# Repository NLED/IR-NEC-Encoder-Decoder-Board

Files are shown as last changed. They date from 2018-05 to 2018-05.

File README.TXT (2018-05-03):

THERE IS NO WARRANTY FOR THE PROGRAM, TO THE EXTENT PERMITTED BY APPLICABLE LAW. 
EXCEPT WHEN OTHERWISE STATED IN WRITING THE COPYRIGHT HOLDERS AND/OR OTHER PARTIES 
PROVIDE THE PROGRAM “AS IS” WITHOUT WARRANTY OF ANY KIND, EITHER EXPRESSED OR IMPLIED,
INCLUDING, BUT NOT LIMITED TO, THE IMPLIED WARRANTIES OF MERCHANTABILITY AND FITNESS 
FOR A PARTICULAR PURPOSE. THE ENTIRE RISK AS TO THE QUALITY AND PERFORMANCE OF THE 
PROGRAM IS WITH YOU. SHOULD THE PROGRAM PROVE DEFECTIVE, YOU ASSUME THE COST OF ALL 
NECESSARY SERVICING, REPAIR OR CORRECTION.

 Original Author: Jeffrey Nygaard
 Company: Northern Lights Electronic Design, LLC
 Date: May 5, 2018
 Contact: JNygaard@NLEDshop.com
 Copyright© 2018 by Northern Lights Electronic Design, LLC. All Rights Reserved
 
;=============          www.NLEDShop.com/addoncards           ============
;=============     www.NorthernLightsElectronicDesign.com       ============

This work is licensed under a Attribution-NonCommercial 4.0 International (CC BY-NC 4.0)
https://creativecommons.org/licenses/by-nc/4.0/legalcode

Free to use for personal use, but please attribute the original author.

Commercial licenses versions are available for a donation of any amount. Contact JNygaard@NLEDshop.com for details.

================================================================================================================

Ready-made devices are available for purchase, and large batch manufacturing of any device can be requested.
Please see the webpage www.NLEDShop.com/addoncards

NLED is available for custom design and manufacturing, please contact via phone or email to discuss your project.

================================================================================================================

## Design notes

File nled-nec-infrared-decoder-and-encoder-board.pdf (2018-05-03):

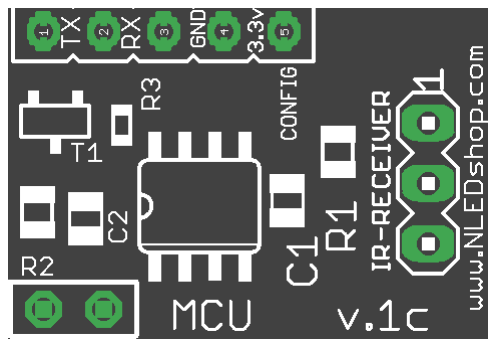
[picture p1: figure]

## Specification:

Input Voltage
Logic Current Draw
Connectors
Connector Spacing
PCB Dimension - Inch
PCB Dimension - Metric
Infrared Remote Compatbility

3.3v or 5v*
< 50mA
Solder Pads
0.1”(2.54mm)
0.8” x 0.55”
20.5mm x 14mm
N.E.C

Receives a raw modulated or demodulated NEC IR signal and converts it into bytes that are sent out the serial port. The serial baud rate is selectable from two default speeds. The default usage mode transmits out a command sequence with framing bytes, address high, address low, and the validated command byte. This device is designed to remove the work load of protocol decoding from the main processor, which could be a PIC, Arduino, FTDI, or other similar serial capable device. It supports full duplex communication when using an I.R. transceiver.

The output protocol was written to be easy to receive. The values 255 & 254 for byte framing followed by data bytes, the repeat codes are indicated by 250 & 253. None of those values would normally be in a NEC command sequence, or at least not in that order. Device expects the extended NEC Protocol, with 16-bit Address, rather than the specified 8-bit address with 8-bit inverse.This device accepts all addresses, and passes the received address to the host device.

## Features:

*Ensure all other connected devices are 5 volt tolerant. That includes IR modules and connected serial devices. *Board lables may say 3.3v but it could also be 5 volt .

- Reduces embedded program work load and simplifies code, this device handles the protocol conversion and outputs easy to understand serial bytes.
- Full transceiver support, recieve and transmit I.R. signals.
- Supports modulated recievers such as the TSOP38238.
- Supports demodulated transcievers such as the TFBS4711.
- Compatible with many standard remote controllers, such as many of the cheaper Chinese ones.
- Compatible with almost all NLED Controllers.
- Very small size.
- Easy to wire remotely, place the receiver where it will best recieve the IR signal.
- Open Source & Open Hardware - Free and open to all for non-commercial use. Contact for commerical.
- Hardware could be used for other IR protocols such as RC-5 or others.
- Standard 8-N-1 at two baud rates available for serial communication.

## NLED NEC Infrared Decoder and Encoder

Pg. 1

TOP

BOTTOM

www.NLEDShop.com/addoncards | www.NorthernLightsElectronicDesign.com

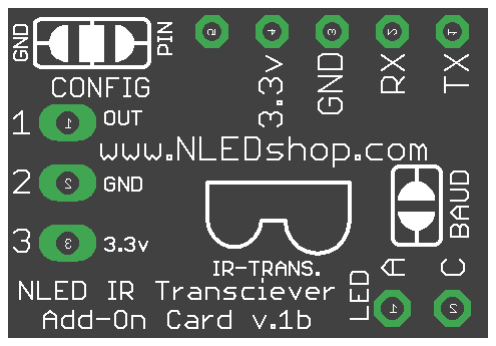
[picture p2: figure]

Datasheet Revision: 1 | Hardware Revision: 1

Copyright Northern Lights Electronic Design, LLC ©2018 - 2/20/2018 - NLED-ADDON-NECIR-V1A - Support@NLEDshop.com

Firmware Revision: 1

This device uses a PIC12F microcontroller to receive infrared signals from remote controls. The received signal is decoded and the NEC protocol is converted to a custom serial packet that is sent out the microcontroller’s UART. The serial packets are easily read and decoded by the receiving device, that device can then decide how to parse the received commands and data.

This device supports demodulated reception from standard IR receiving modules. And modulated reception and transmission from transcievers.

Code Reception UART Output: 255 -> 254 -> AdrMSB -> AdrLSB -> Remote Key Number

Note: NEC sends LSB first for extended address, UART transmits MSB first since that is a common standard.

Example:
AddressLow - 0x00, AddressHi - 0xEF, KeyID#4(key IDnumbers start at 0)
255 -> 254 -> 239(0xEF) -> 0(0x00) -> 4
Repeat: 250 -> 253, repeats while key is being held pressed.

## Reception Usage Description

## Firmware Info

The firmware is written for the NEC protocol, which uses a 38KHz carrier frequency. Using the SMD solder jumpers, the function can be selected.

CONFIG Jumper: Connects to Configuration Mode and MCLR(for ICSP programming) function. For ICSP programming, the jumper must be tied to “PIN”. For application usage, the jumper selects if the device should expect a moduled signal(from the transciever) or a demodulated signal(from the receiver). Connecting the jumper to “PIN”(or left unconnected) will select demoduled receiver functions, if the jumper is tied to “GND” a modulated signal is expected.

BAUD Jumper: Selects either slow or fast baud rate. The default firmwae uses 19,200 baud for slow, and 250,000 baud for fast. Leave jumper open/untied for slow baud rate, and close the jumper for fast baud rate.

This device can also transmit a NEC control command. Either an I.R. LED must be connected to the LED pads, or the transceiver must be used. The protocol is not much different than receiving, the host device just sends a series of serial bytes to the device. The serial bytes include an unlock sequence, followed by the command IDs the user wants to send.

Serial Transmission From Host: 251 -> 122 -> 252 -> 123 -> AdrMSB -> AdrLSB -> Command -> Number of repeats

The (251 -> 122 -> 252 -> 123) is the unlock sequence, required to frame the data and validate a command to the device.

Note: If compiling the firmware make sure “cEnableNECTransmission” is defined. Also the firmware has another flag that tells the firmware to ignore reception during transmisison to prevent receiving its own command.

## Transmission Usage Description

This project’s source files, including Eagle schematic and board files, MPLABX project, and support documents are all open source and available for free.

The project is released under Attribution-NonCommercial 4.0 International. A commercial licence is available as donation-ware of any amount. Contact JNygaard@NLEDshop.com for details.

## Open Source / Open Platform

## Part Selection

MCU:
For Infrared Reception Only PIC12F1822 or PIC12F1840

For Full Duplex Infrared:
PIC12F1572

These are not the only options.

Infrared Receiver/Transciever: For Infrared Reception Only: TSOP3828

For Full Duplex Infrared:
Vishay TFBS4711

These are not the only options.

C1 & C2 - 01.uF, 0805, >=6.3vdc

For Transceiver/Transmission Use:

R1 - 47ohm, 0805
R2 - 18 to 47 ohm, 0805
R3 - 5 to 10 ohm, 0805
T1 - NPN Transistor, BSR17A, SOT-23

The I.R. LED is used for transmitting command codes, a standard 5mm dome LED is recommended. Higher power I.R. LEDs could be used, check the transistor rating and current limiting resistor values. The I.R. LED can be wired to the device or can be mounted directly to the circuit board.

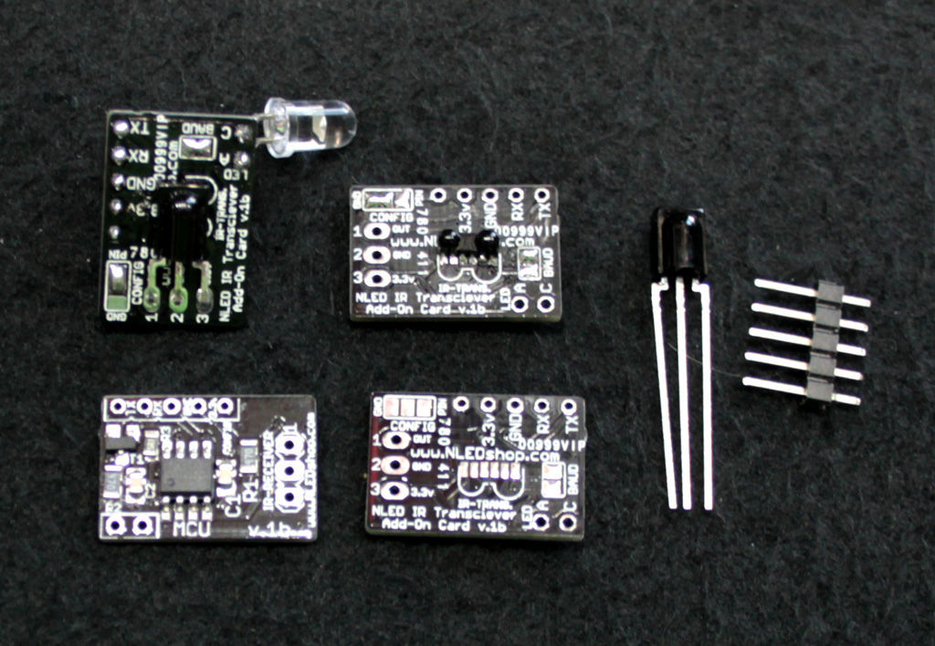
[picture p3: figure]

## Assembly Options

Image to the left is a few ways to configure the device and the parts that could be used.

## Hardware Diagrams

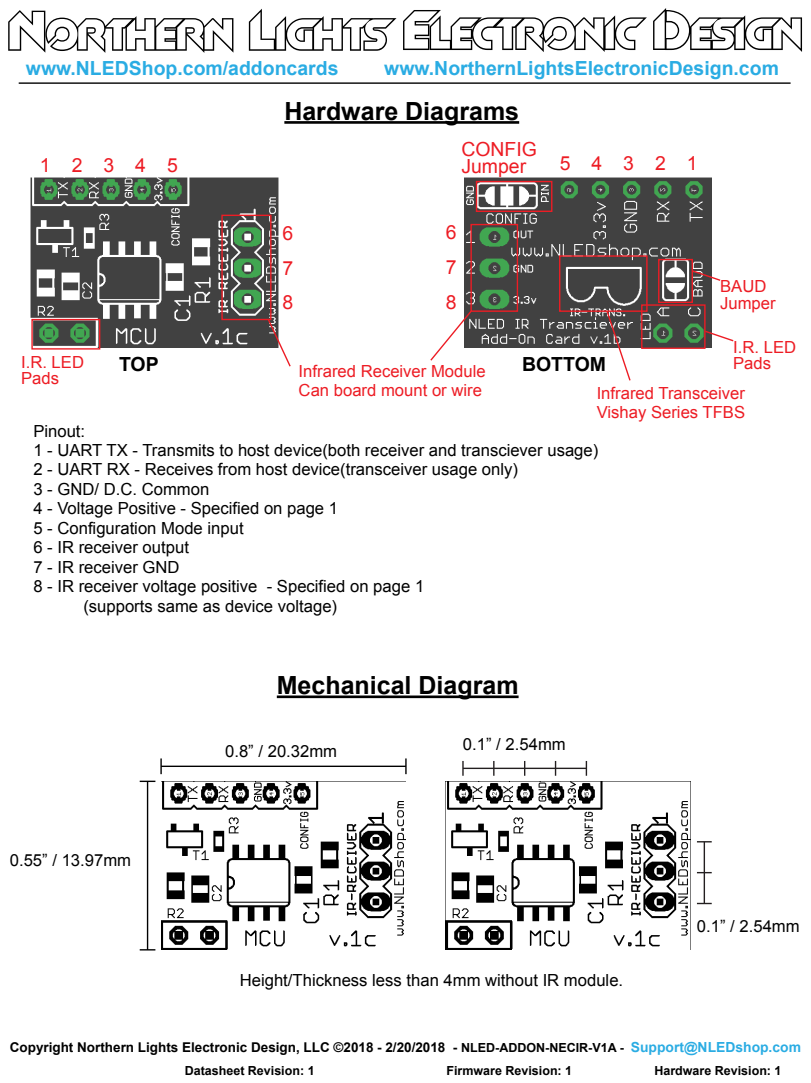
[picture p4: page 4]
TOP; BOTTOM; CONFIG Jumper; BAUD Jumper; I.R. LED; Pads; Mechanical Diagram

Infrared Receiver Module
Can board mount or wire

Infrared Transceiver
Vishay Series TFBS

Pinout:
1 - UART TX - Transmits to host device(both receiver and transciever usage)
2 - UART RX - Receives from host device(transceiver usage only)
3 - GND/ D.C. Common
4 - Voltage Positive - Specified on page 1
5 - Configuration Mode input
6 - IR receiver output
7 - IR receiver GND
8 - IR receiver voltage positive - Specified on page 1

(supports same as device voltage)

Height/Thickness less than 4mm without IR module.

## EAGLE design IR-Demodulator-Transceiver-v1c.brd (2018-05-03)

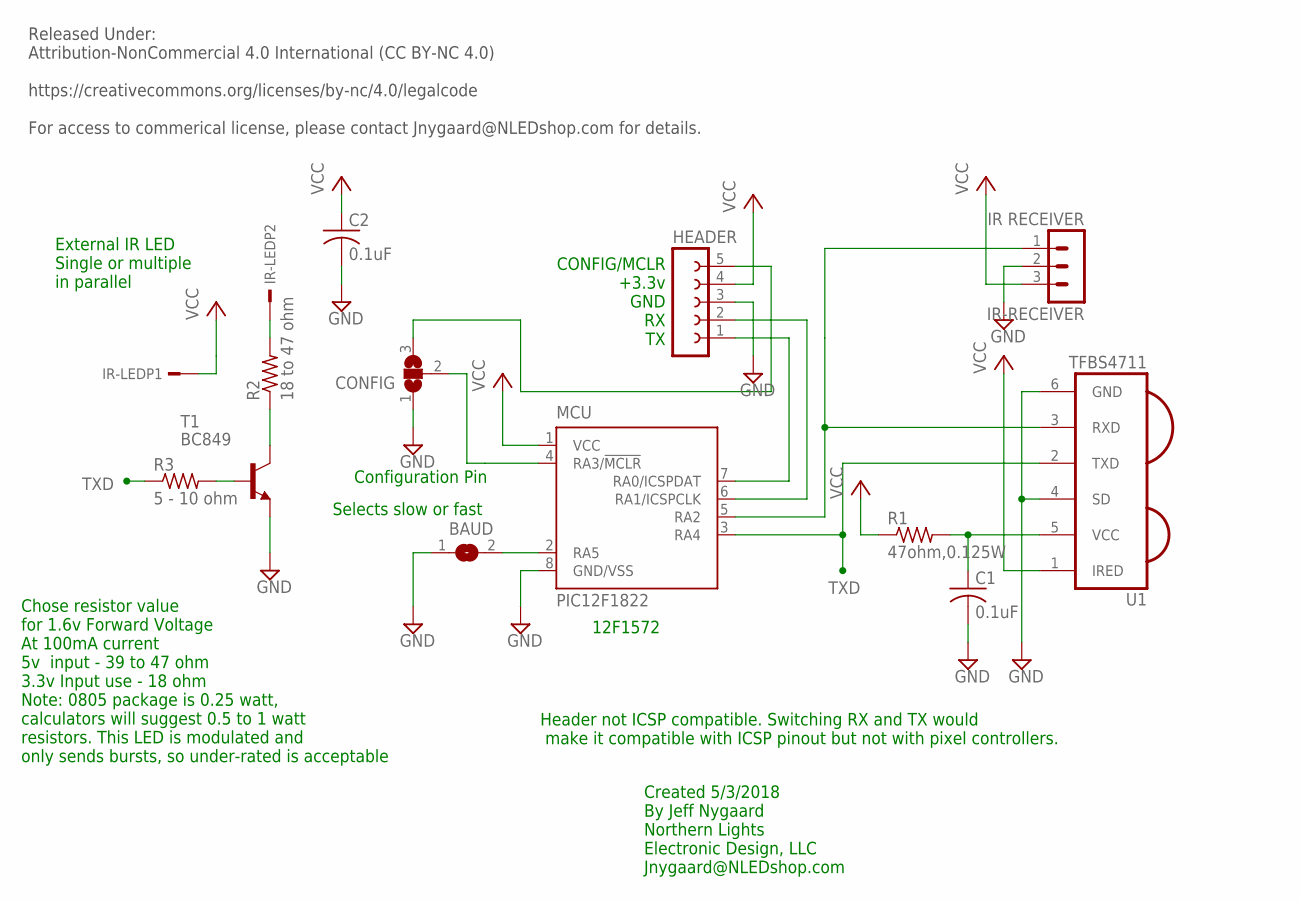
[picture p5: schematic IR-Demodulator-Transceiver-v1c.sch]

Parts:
BAUD: SJ
C1, C2: 0.1uF; C0805
CONFIG: SJ2W; SJ_2
HEADER: FE05-1
IR-LED: HEADER-2X1
IR-RECEIVER: IR RECEIVER; MA03-1
MCU: PIC12F1822; SOIC-8
R1: 47ohm,0.125W; R0805
R2: 18 to 47 ohm; R0805
R3: 5 - 10 ohm; R0603
T1: BC849; SOT23
U1: TFBS4711

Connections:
GND: BAUD.1, C1.2, C2.2, CONFIG.1, HEADER.3, IR-RECEIVER.2, MCU.8 (GND/VSS), T1.2 (E), U1.4 (SD), U1.6 (GND)
IRRX: IR-RECEIVER.1, MCU.5 (RA2), U1.3 (RXD)
unnamed: R3.2, T1.1 (B)
unnamed: BAUD.2, MCU.2 (RA5)
unnamed: C1.1, R1.2, U1.5 (VCC)
unnamed: CONFIG.3, HEADER.5
unnamed: HEADER.1, MCU.7 (RA0/ICSPDAT)
unnamed: HEADER.2, MCU.6 (RA1/ICSPCLK)
unnamed: CONFIG.2, MCU.4 (RA3/!MCLR)
unnamed: IR-LED.2, R2.2
unnamed: R2.1, T1.3 (C)
TXD: MCU.3 (RA4), R3.1, U1.2 (TXD)
VCC: C2.1, HEADER.4, IR-LED.1, IR-RECEIVER.3, MCU.1 (VCC), R1.1, U1.1 (IRED)

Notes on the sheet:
CONFIG/MCLR +3.3v GND RX TX
Selects slow or fast
Configuration Pin
Header not ICSP compatible. Switching RX and TX would make it compatible with ICSP pinout but not with pixel controllers.
External IR LED Single or multiple in parallel
Chose resistor value for 1.6v Forward Voltage At 100mA current 5v input - 39 to 47 ohm 3.3v Input use - 18 ohm Note: 0805 package is 0.25 watt, calculators will suggest 0.5 to 1 watt resistors. This LED is modulated and only sends bursts, so under-rated is acceptable
12F1572
Released Under: Attribution-NonCommercial 4.0 International (CC BY-NC 4.0) https://creativecommons.org/licenses/by-nc/4.0/legalcode For access to commerical license, please contact Jnygaard@NLEDshop.com for details.
Created 5/3/2018 By Jeff Nygaard Northern Lights Electronic Design, LLC Jnygaard@NLEDshop.com

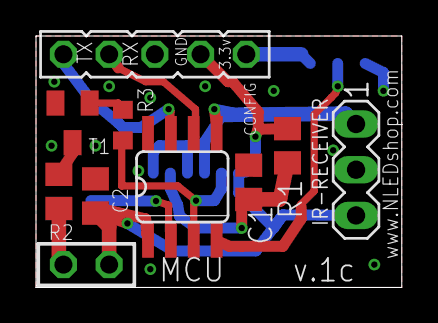
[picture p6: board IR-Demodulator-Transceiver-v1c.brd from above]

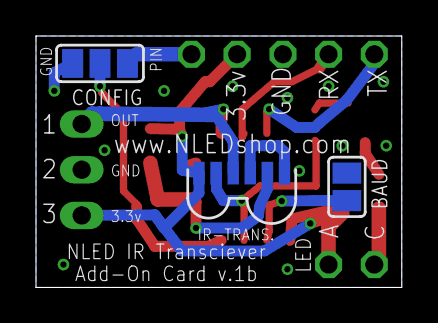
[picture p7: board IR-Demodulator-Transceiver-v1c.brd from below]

Board: 2 copper layers, 20.3 x 14.0 mm, 13 parts (3 on the bottom side), 13 nets.

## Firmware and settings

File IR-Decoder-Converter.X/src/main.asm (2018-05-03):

;*******************************************************************************                                        *
;                                                                              *
;    SOFTWARE IS PROVIDED "AS IS".  Northern Lights Electronic Design, LLC AND ITS LICENSORS EXPRESSLY      *
;    DISCLAIM ANY WARRANTY OF ANY KIND, WHETHER EXPRESS OR IMPLIED, INCLUDING  *
;    BUT NOT LIMITED TO, THE IMPLIED WARRANTIES OF MERCHANTABILITY, FITNESS    *
;    FOR A PARTICULAR PURPOSE, OR NON-INFRINGEMENT. IN NO EVENT SHALL          *
;    Northern Lights Electronic Design, LLC OR ITS LICENSORS BE LIABLE FOR ANY INCIDENTAL, SPECIAL,         *
;    INDIRECT OR CONSEQUENTIAL DAMAGES, LOST PROFITS OR LOST DATA, HARM TO     *
;    YOUR EQUIPMENT, COST OF PROCUREMENT OF SUBSTITUTE GOODS, TECHNOLOGY OR    *
;    SERVICES, ANY CLAIMS BY THIRD PARTIES (INCLUDING BUT NOT LIMITED TO ANY   *
;    DEFENSE THEREOF), ANY CLAIMS FOR INDEMNITY OR CONTRIBUTION, OR OTHER      *
;    SIMILAR COSTS.                                                            *
;                                                                              *
;    To the fullest extend allowed by law, Northern Lights Electronic Design, LLC and its licensors         *
;    liability shall not exceed the amount of fee, if any, that you have paid directly to NLED to use this software.
;                                                                              *
;    Northern Lights Electronic Design, LLC PROVIDES THIS SOFTWARE CONDITIONALLY UPON YOUR ACCEPTANCE OF
;    THESE TERMS.                                                              *
;                                                                              *
; Original Author: Jeffrey Nygaard
; Company: Northern Lights Electronic Design, LLC
; Contact: JNygaard@NLEDShop.com
; Date Updated: May  5, 2018
; Webpage: www.NLEDShop.com
;Title: NLED Modulated NEC Infrared Decoder and Encoder
;Project IDE: MPLABX v4.05
;Compiler: MPASM v5.76 (shouldn't ever matter)
;License: Attribution-NonCommercial 4.0 International (CC BY-NC 4.0) https://creativecommons.org/licenses/by-nc/4.0/legalcode


;Supported Processors For Reception(short list): PIC12F1822, PIC12F1840
;Supported Processors For Full Duplex(short list): PIC12F1572
;MCU Requirements:
;   - TMR0, TMR1, TMR2
;   - one additional 16-bit timer required for transmission - used here is a unused PWM with dedicated timer
;   - 1x UART
;   - 1x PWM output if transmission is utilized
;   - 32Mhz or 8 MIPs - otherwise timings would be all wrong

;Description:
;PLEASE READ THE README.TXT FILE THAT WAS INCLUDED 

;Expects the extended NEC Protocol, with 16-bit Address, rather than a 8-bit address with 8-bit inverse
;Note: NEC sends LSB first for extended address, UART transmits MSB first since that is the common standard

;Reception UART Transmits: 255 -> 254 -> AdrMSB -> AdrLSB -> Key Number
;Example: AddressLow - 0x00, AddressHi - 0xEF, KeyID#4(key IDnumbers start at 0)
;       255 -> 254 -> 239(0xEF) -> 0(0x00) -> 4
;   Repeat: 250 -> 253, repeats while key is held

;Transmission UART Receives: 
;	251 -> 122 -> 252 -> 123 -> AdrMSB -> AdrLSB - Command ID -> Number of Repeats
;Example: 
;	AddressLow - 0x00, AddressHi - 0xEF, KeyID#4(key IDnumbers start at 0), 2 Repeats
;	251 -> 122 -> 252 -> 123 -> 239(0xEF) -> 0(0x00) - 4  -> 2

;How it Works:
;   A lot of confusing code. But basically a progressive state machine reads the NEC protocol step by step. All interrupt
;       based with some program loop data crunching. Demodulated is straight forward, modulated reception is even
;       more confusing, it either counts carrier pulses to establish a hi/low time, or uses timers.
;   I learned a lot doing this project, most of all, I learned I should have done things completely differently. Not worth rewriting.

;Usage:
;   1. Decide what functions you will need and choose a I.R. reciever module, transciever, and/or I.R. LED
;   2. See datasheet for specifics.
;   3. Leave BAUD jumper open or closed to select the baud rate
;   4. To build a HEX file, select the compile DEFINEs to select usage.
;   5. Program HEX file
;   6. Power it up, connect serial host device and start using, if it doesn't work double check Baud rate settings

;Found these projects and links useful:
;https://reference.digilentinc.com/learn/courses/unit-5/start
;http://www.sbprojects.com/knowledge/ir/nec.php
;https://www.laser.com/dhouston/ir-rf_fundamentals.html
;http://www.ti.com/lit/an/slaa644b/slaa644b.pdf
;https://www.vishay.com/docs/80071/dataform.pdf

;*******************************************************************************

;Processor Notes:
;At 8 MIPS it is 125nS instruction time
;TMR2 at 1:1, 1:1, takes 31.875uS for PR2 of 255
;Max TMR2 duration is 32.64mS
;TMR0 - Pulse Timer
;TMR1 - reset timer
;TMR2 - master timer
;UART - connected to MCU
;PWM2 - IRTX

;RA0/ICSPDAT = TX
;RA1/ICSPCLK = RX
;RA2 = IRRX - INT pin
;RA3/MCLR = GPIO input - Configuration Mode IO pin, tie to HEADER or GND, pulled high - selects modulated or demodulated usage.
;RA4 = IRTX - PWM2
;RA5 = GPIO input - Baud rate Jumper, pulled high. Open = 19200 baud, Closed = 250K baud

;NOTE: On the v1b & v1c hardware  ICSP CLK and DAT are physically swapped  to maintain compatibility with NLED addon
;           headers and connectors. That makes it harder to flash the program, but otherwise is not an issue.

;Protocol Notes:
;38Khz carrier is 26.31uS officially, about 2.6uS low, 24.6uS high on my remote as measured
;562.5uS bit time, which is 21? carrier cycles

;NEC Main Code
;a 9ms leading pulse burst (16 times the pulse burst length used for a logical data bit)
;a 4.5ms space
;the 8-bit address for the receiving device
;the 8-bit logical inverse of the address
;the 8-bit command
;the 8-bit logical inverse of the command
;a final 562.5µs pulse burst to signify the end of message transmission.
;bits take 1.125mS for 0, and 2.25mS for 1

;REPEAT CODES
;If the key on the remote controller is kept depressed, a repeat code will be issued, typically around 40ms after the 
;    pulse burst that signified the end of the message. A repeat code will continue to be sent out at 108ms intervals,
;    until the key is finally released. The repeat code consists of the following, in order:
;a 9ms leading pulse burst
;a 2.25ms space
;a 562.5µs pulse burst to mark the end of the space (and hence end of the transmitted repeat code).

;*******************************************************************************
; Start  Defines
;*******************************************************************************

#include "defines.inc" ;hardware profile, RAM defines, software constants

;*******************************************************************************
;Start Compile Time Flags
;Uncomment to enable, comment out to disable
;*******************************************************************************

;Will only work on some processors, see MCU requirements
#define cEnableNECTransmission
#define cPreventTXReception ;will disable reception when transmitting, preventing a transciever from receiving its 
                                                   ;    own message but it could miss receiving a message during the process. Once the 
                                                    ;   message is transmitted, reception continues normally.

;edit these to suit, on init.inc there is a list of the other available baud rates with their SPBRG values
#define cSlowBaudRate .103 ;19200 baud
#define cFastBaudRate .7 ;250k baud

;*******************************************************************************
; Reset Vector
;*******************************************************************************

RES_VECT  CODE    0x0000            ; processor reset vector
    GOTO    Initialize                   ; go to beginning of program

;*******************************************************************************

ISR_VECT  CODE    0x0004           ; processor ISR vector
;The latency for synchronous interrupts is three or four instruction cycles. For
;asynchronous interrupts, the latency is three to fiveinstruction cycles, depending on when the interrupt occurs.

;Critical/Core registers are automatically saved to the shadow registers, see datasheet for listing
;-----------------------------------------------------------------------------------------

#ifdef cEnableNECTransmission
    ;For Transmission use, check if UART has received any bytes
    banksel PIR1
    BTFSC PIR1, RCIF
        goto HandleReceivedByte ; check if needs paging, retfie out
#endif

;-----------------------------------------------------------------------------------------

    ;INT -  then it is a edge detect interrupt
    BCF INTCON, INTF ;clear interrupt flag bit

;-----------------------------------------------------------------------------------------

#ifdef cPreventTXReception
    BTFSS DataWaitingTransmission
        bra skipReceptionDisable
    ;a interrupt has fired, but device is transmitting a message, could be its own message, ignore
    banksel PIR1
    clrf PIR1 ;clear all potential interrupts(excluding INTF which was done above, not great but works
    retfie
skipReceptionDisable
#endif

;-----------------------------------------------------------------------------------------

    banksel PIR1
    BTFSS PIR1, TMR1IF
        bra isrSkip
    ;TMR1 IF flag is set

    BTFSS RepeatFlag ;check if waiting for repeat frames
        bra skipRepeat
    ;repeat flag is set, that means it needs more time to wait for repeat packets before timing out
    BCF RepeatFlag ;clear flag, only toggles once, next time it times out
    BCF PIR1, TMR1IF

        bra isrSkip

skipRepeat
    ;TMR1 has interrupted, reset State Machine and wait for next remote command
    BCF PIR1, TMR1IF
    clrf ReceiveState

    banksel PIE1
    BTFSS PIE1, TMR1IE
        bra isrSkip
    ;reset timer has timed out, turn off enable and wait for next remote command
    BCF PIE1, TMR1IE    ;if enabled turn off IE and retfie
        retfie
    ;TMR1 and RepeatFlag handled, continue ISR

isrSkip ;no TMR1 interrupt, continue
    BTFSC ModulationConvertFlag ;flag set only at power up
    goto  ReadDemodulatedEncoding
    ;else read Modulated Encoding
    goto ReadModulatedEncoding
    ;never gets here, both above functions RETFIE

;*******************************************************************************
; MAIN PROGRAM
;*******************************************************************************

;MAIN_PROG CODE                      ; let linker place main program - screws things up

START

    BANK1
    clrf transmitFuncState
    BANK0
    clrf ReceiveState ;set to initial state

    BCF INTCON, IOCIF
    BCF INTCON, INTF ;clear interrupt flag bit before setting GIE so it doens't interrupt right away
    BSF INTCON, GIE ;enables global interrupts
    BSF INTCON, PEIE ;TMR1 won't interrupt unless this is set, but INT will

MainLoop
    clrwdt

   BTFSC ConvertToBytesFlag ;waits til validated NEC code has been received
   call FunctionToSerialBytes

    #ifdef cEnableNECTransmission
    BTFSC DataWaitingTransmission
    call TransmitModulatedEncoding
    #endif

      bra MainLoop

;*******************************************************************************

FunctionToSerialBytes ;both reception methods use this same function
;converts the 32 bytes of 0 or 1 as a bit, into 4 bytes(8x4=32)
    BCF ConvertToBytesFlag ;clear flag

    ;set FSR1 to starting byte
    movlw 0x20 ;address of bank 0 RAM
    movwf FSR1H
    movlw 0x00 ;address of bank 0 RAM
    movwf FSR1L

    ;start converting bytes to bits
    call FunctionConvertByte
    movwf ConvertedByte1 ;AddressLo
    call FunctionConvertByte
    movwf ConvertedByte2 ;AddressHi
    call FunctionConvertByte
    movwf ConvertedByte3 ;Command
    call FunctionConvertByte
    movwf ConvertedByte4 ;Command Inverse
    ;now all converted to normal bit order ready to use

    ;start sending converted values out UART
    ;Choice of two output functions that sends the data out
    bra SendCommandCode ;builds a command code sequence with byte framing, checks command inverse
    ;bra SendRawBytes ;sends the raw, AddressLo, AddressHi, Command, Command Inverse
        ;both functions return to program loop, so use BRA instead of CALL

;-----------------------------------------------------------------------------------------

FunctionConvertByte
    ;NEC sends LSB first, reads each stored byte in RAM and converts it to a bit
    clrf Scratch

    MOVIW FSR1++ ;move FSR byte value to working, post increment
    BTFSC WREG, 0 ;check if logical 1 or 0 stored in byte
    BSF Scratch, 0

    MOVIW FSR1++ ;move FSR byte value to working, post increment
    BTFSC WREG, 0 ;check if logical 1 or 0 stored in byte
    BSF Scratch, 1

    MOVIW FSR1++ ;move FSR byte value to working, post increment
    BTFSC WREG, 0 ;check if logical 1 or 0 stored in byte
    BSF Scratch,2

    MOVIW FSR1++ ;move FSR byte value to working, post increment
    BTFSC WREG, 0 ;check if logical 1 or 0 stored in byte
    BSF Scratch,3

    MOVIW FSR1++ ;move FSR byte value to working, post increment
    BTFSC WREG, 0 ;check if logical 1 or 0 stored in byte
    BSF Scratch,4

    MOVIW FSR1++ ;move FSR byte value to working, post increment
    BTFSC WREG, 0 ;check if logical 1 or 0 stored in byte
    BSF Scratch,5

    MOVIW FSR1++ ;move FSR byte value to working, post increment
    BTFSC WREG, 0 ;check if logical 1 or 0 stored in byte
    BSF Scratch,6

    MOVIW FSR1++ ;move FSR byte value to working, post increment
    BTFSC WREG, 0 ;check if logical 1 or 0 stored in byte
    BSF Scratch,7

    movfw Scratch ;returns with result in WREG
        return

;*******************************************************************************

SendCommandCode
    ;uses the received NEC data bytes to build a command to send to the main MCU
    ; This assumes that the addressing is done using the non-standard 16-bit method, 
        ; rather than 8-bit address + 8-bit address inverse.

    ;It is easier to update the main MCU, so this will send the IR remote address and the main MCU can
        ; choose to use or ignore if the remote is the wrong address. Or it can use all addresses, main MCU's choice

    ;first check if the command and command inverse match
    movfw ConvertedByte4
    COMF WREG, w ;result stored in WREG
    ;WREG holds inverted Command Inverse, so should be same as Command
    xorwf ConvertedByte3, w
    BTFSS STATUS, Z
        return ;leave if the Command and Command Inverse are mismatched, could handle or send error

    ;sends: 255 -> 254 -> AddressHi -> AddressLo -> Command

    banksel TXREG
    movlw .255 ;send framing byte
    movwf TXREG

    BTFSS TXSTA, TRMT ;check if TSR is empty, wait if its not
    bra $-1

    banksel TXREG
    movlw .254  ;send framing byte
    movwf TXREG

    BTFSS TXSTA, TRMT ;check if TSR is empty, wait if its not
    bra $-1
    ;sent framing bytes, could have done a BREAK or similar

    banksel TXREG
    movfw ConvertedByte2 ;sending Address MSB first that is more standard
    movwf TXREG

    BTFSS TXSTA, TRMT ;check if TSR is empty, wait if its not
    bra $-1

    banksel TXREG
    movfw ConvertedByte1 ;then Address LSB
    movwf TXREG

    BTFSS TXSTA, TRMT ;check if TSR is empty, wait if its not
    bra $-1

    banksel TXREG
    movfw ConvertedByte3 ; 
    movwf TXREG
    ; all done sending bytes
        return ; to program loop

;-----------------------------------------------------------------------------------------

SendRawBytes
    ;sends the raw, AddressLo, AddressHi, Command, Command Inverse
    banksel TXREG
    movfw ConvertedByte1
    movwf TXREG

    BTFSS TXSTA, TRMT ;check if TSR is empty, wait if its not
    bra $-1

    banksel TXREG
    movfw ConvertedByte2
    movwf TXREG

    BTFSS TXSTA, TRMT ;check if TSR is empty, wait if its not
    bra $-1

    banksel TXREG
    movfw ConvertedByte3
    movwf TXREG

    BTFSS TXSTA, TRMT ;check if TSR is empty, wait if its not
    bra $-1

    banksel TXREG
    movfw ConvertedByte4
    movwf TXREG
    ; all done sending bytes
        return ; to program loop

;*******************************************************************************
;External Assembly Includes - Easy way to break code onto multiple files but keep memory linear to avoid page boundaries
;*******************************************************************************

#include "modulated-reception.inc"
#include "demodulated-reception.inc"

#ifdef cEnableNECTransmission
#include "transmission.inc"
#endif

#include "init.inc"

;*******************************************************************************

    END

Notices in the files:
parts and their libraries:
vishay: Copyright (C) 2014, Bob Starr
